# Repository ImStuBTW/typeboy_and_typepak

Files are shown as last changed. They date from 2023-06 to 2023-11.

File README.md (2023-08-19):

# The TypeBoy & TypePak

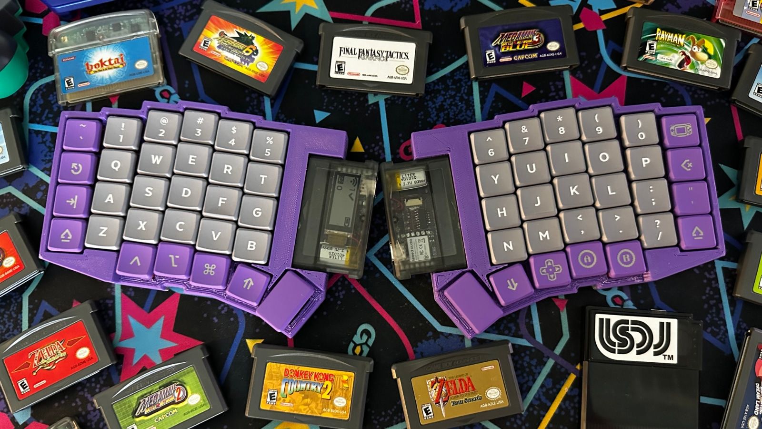
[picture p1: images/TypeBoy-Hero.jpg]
The TypeBoy & TypePak Laying Next To Several GBA Cartridges.


The TypeBoy is a fairly standard split ergonomic keyboard with a very non-standard microcontroller setup. Your eyes don't deceive you: This is a keyboard that needs a Game Boy Advance cartridge to function.

More specifically, it needs a TypePak! I've been spending a lot of time in the Ergogen keyboard layout generator lately, and I recently finished building a Sanni Open Source Cartridge Reader. These two worlds collided in my head and it dawned on me that a keyboard's microcontroller stack could probably fit in the shell of a Game Boy cartridge. A bit of tinkering in KiCAD later, and suddenly this monstrosity the TypePak was born.

## [The TypePak](typepak/README.md)

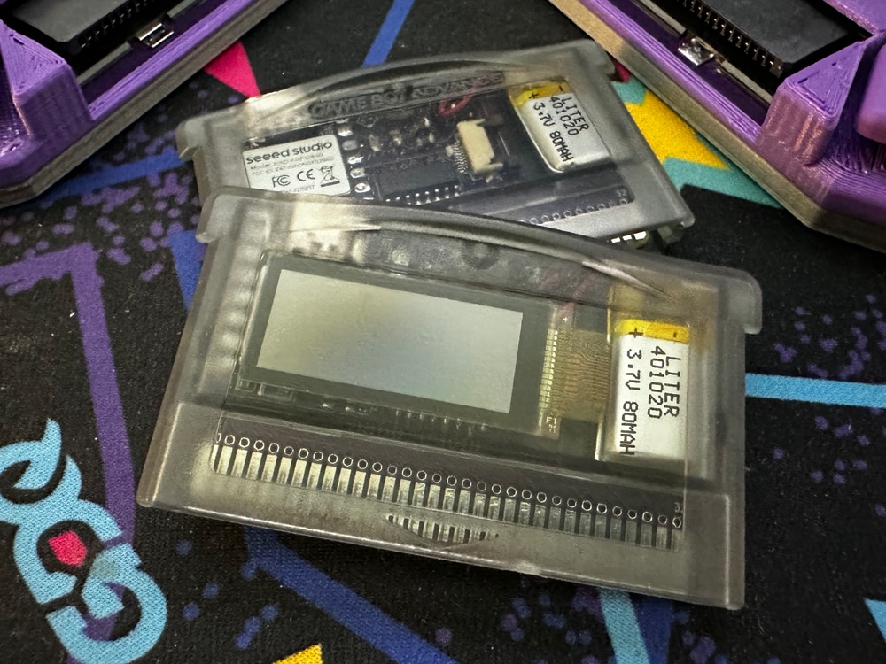
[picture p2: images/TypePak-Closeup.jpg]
The TypePak, a microcontroller and black and white display inside of a Game Boy Advance cartridge.


The TypePak is a keyboard daughterboard with a XIAO nRF52840 Bluetooth microcontroller, a SN74HC595DT shift register, a LS011B7DH03 Sharp Memory Display, and a 401020 lipo battery designed to be housed inside of a standard Game Boy Advance cartridge. Every pin is broken out in case you find some novel use for SPI, or chose not to use the screen. The battery trace and reset pins are also broken out so that you can put a power and reset switch on the main keyboard. You'll need to use a tool similar to a Dremel in order to cut a USB-C port in the side of the cartridge shell.

## [The TypeBoy](typeboy/README.md)

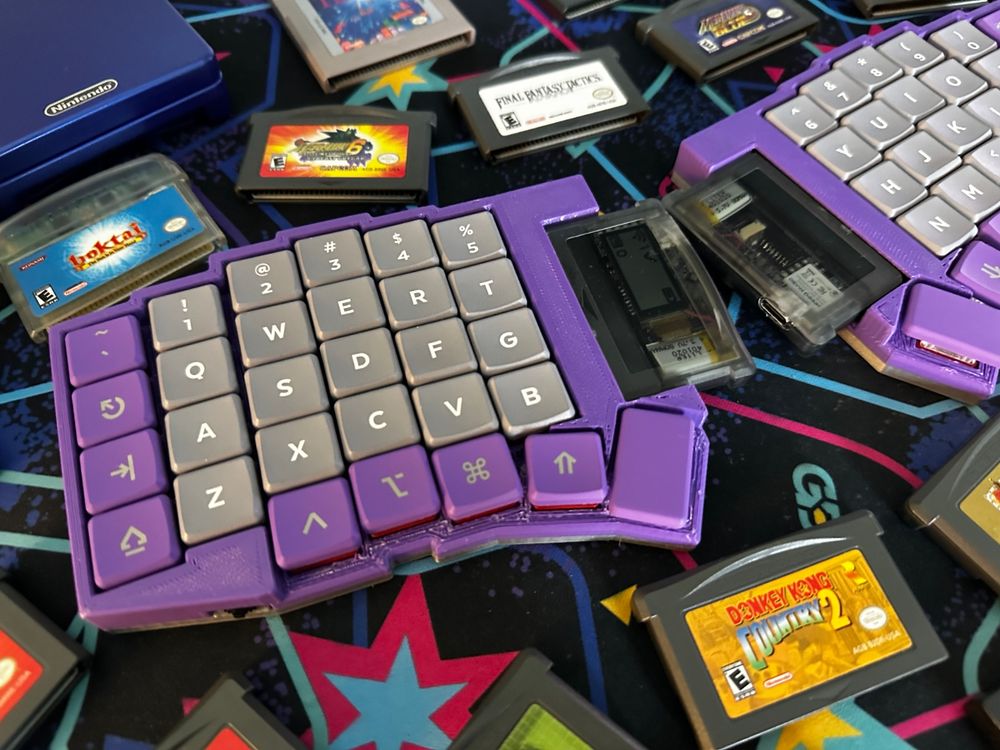
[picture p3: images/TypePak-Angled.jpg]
The TypeBoy, a keyboard with a cartridge slot.


The TypeBoy is a typical split keyboard with a 6x4+5 column staggered layout. The big difference being that it has a 32 pin slot for the Game Boy Advance cartridge. The connector appears on both sides of the board, with traces and vias making the connector pinout reversible. The other notable feature is a SLLB510100 thumb switch.

## [ZMK-Config](/zmk-config)

The ZMK wireless keyboard firmware configuration for this board is relatively standard. The software doesn't have any clue that it's being housed on an odd removable cartridge. Items to note are the LS011B7DH03 display using ZMK's built in Display support instead of the Nice!View wrapper one may be more familiar with, 74HC595 shift register support to add additional column output pins, and a [composite](https://zmk.dev/docs/config/kscan#composite-driver) key scan driver for using both a traditional keyboard matrix and direct pin reading for the thumb wheel.

## Acknowledgements

The TypeBoy isn't the first mechanical keyboard which takes microcontroller cartridges. [mujimanic](https://www.reddit.com/user/mujimanic/)'s [Giga40](https://www.reddit.com/r/MechanicalKeyboards/comments/kut2nk/now_youre_playing_with_power_giga40_power/) keyboard design and it's Famicom cartridges helped prove a low-profile Game Boy-centric version of this idea was worth pursuing.

The TypePak's display connector circuit is based off of [karnadii](https://github.com/karnadii)'s [Sharp Memory Display breakout board](https://github.com/karnadii/sharp_memory_display_breakout) design. The TypePak's PCB is based off of templates from [djedditt](https://github.com/djedditt/)'s [kicad-gamepaks](https://github.com/djedditt/kicad-gamepaks) library. The Game Boy cartridge slot KiCAD footprint was used from [Martin Refseth](https://github.com/HDR)'s [Game Boy KiCad Library](https://github.com/HDR/Game-Boy-KiCad-Library).

As usual, thanks to the [Absolem Club Discord](https://discord.gg/DbCfZfZ) and their #Ergogen channel for answering my endless onslaught of questions. Particularly special thanks to [Pete Johanson](https://github.com/petejohanson) for assisting with some ZMK troubleshooting when the low profile rotary encoders were giving me trouble. The ZMK firmware is heavily influenced by previous configs by [GEIST](https://github.com/GEIGEIGEIST/zmk-config-totem/tree/master/config), [Pete Johanson](https://github.com/petejohanson/zaphod-config/tree/main/boards/shields/zaphod_lite), and [JonMuller](https://github.com/JonMuller/gerbers/tree/main/corne-choc-xiao).

This keyboard is another derivative of [Josef Adamčík](https://josef-adamcik.cz/)'s original [Sofle Keyboard](https://josefadamcik.github.io/SofleKeyboard/) layout. I need to start experimenting with other layouts at this point, but it's hard to beat that thumb cluster.

Finally, another shout out to [GEIST](https://github.com/GEIGEIGEIST), [Freya](https://github.com/freya-irl), [Bubbleology](https://github.com/bubbleology) for their work on the [TOTEM](https://github.com/GEIGEIGEIST/TOTEM) keyboard's case. It was a big inspiration for this build, and they pulled the concept off way better than I did.

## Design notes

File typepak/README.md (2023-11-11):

# The TypePak

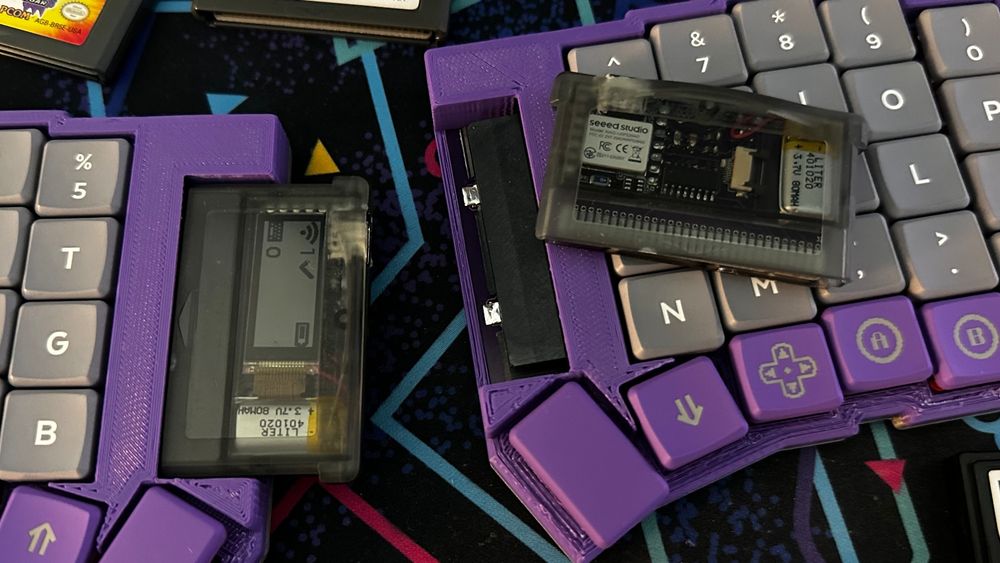
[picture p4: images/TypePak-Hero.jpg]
The TypePak microcontroller cartridge.


The TypePak is a custom keyboard controller PCB housed inside of an aftermarket Game Boy Advance cartridge shell. It features Bluetooth connectivity, ZMK support, a low-power monochrome display, a built in LiPo battery, 9 GPIO pins, and 8 dedicated output pins. Simply slot the TypePak into a keyboard with a compatible Game Boy cartridge slot, flip the power switch, and you've got yourself a working wireless keyboard. (After flashing the appropriate firmware and keymap, naturally.)

Unlike its companion TypeBoy, the TypePak was designed in KiCAD from scratch. Sadly there aren't any esoteric Game Boy cartridge generators just yet. This repository contains a standard KiCAD project. There's a schematic, a routed PCB, and a Gerber file.

## Layout & Pinout

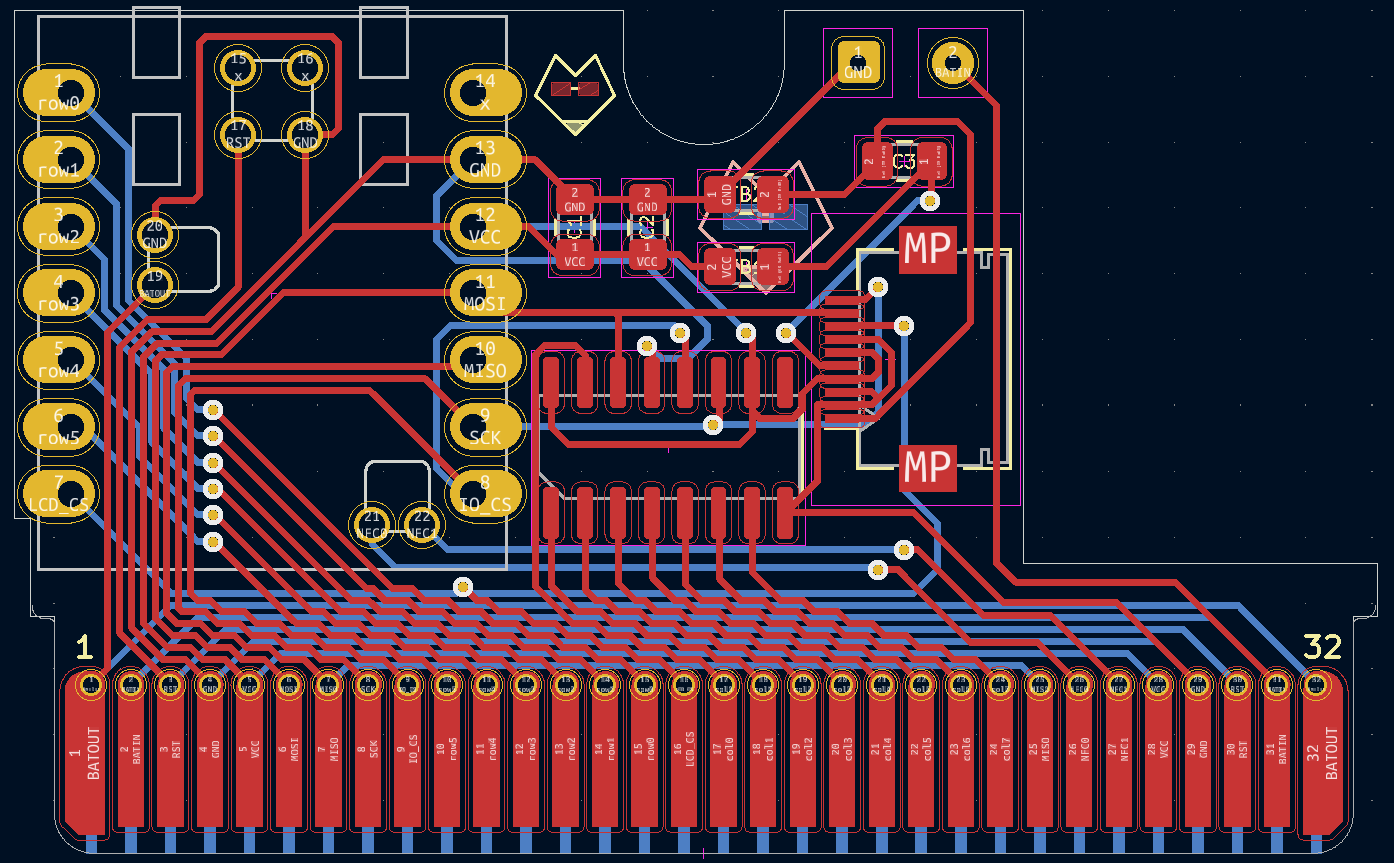
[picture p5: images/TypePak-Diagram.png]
The TypePak PCB layout.


The heart of the TypePak is a XIAO nRF52840 microcontroller. It handles all of the Bluetooth communication, the wireless battery charging, and USB connectivity. The XIAO "BLE" famously has several pins mounted in the middle of the board on its underside, so the TypePak has several small holes in the PCB to reach the reset, power, and NFC pins.

There's a few additional pieces of hardware mounted onto the board. The TypePak features a LS011B7DH03 Sharp Memory Display. This is the same module found on the Nice!View keyboard display, but instead leverages karnadii's excellent [sharp_memory_display_breakout](https://github.com/karnadii/sharp_memory_display_breakout) circuit design. The microcontroller also takes advantage of a 74HC595 shift register to provide several more output pins. All of this is powered by a 401020 LiPo battery.

A Game Boy cartridge has 32 pins on its edge connector. The XIAO nRF52840 and the shift register have a total of 26 pins. Rather than leave twenty precent of the TypePak's cartridge pins unused, several of the important pins are exposed on both ends of the cartridge's edge connector. The battery output, power pins, reset pins, and a few others are duplicated so that you can more easily route some of the support hardware on your keyboard PCB.

Speaking of which, the TypePak does not have a built in power switch or reset button of its own. (Technically the XIAO does have a reset button, but it's underneath the cartridge's plastic casing.) You'll need to create out these components on the keyboard itself. The whole idea of this setup is to evoke the stylings of a classic Game Boy, so a large chunky power switch is honestly a welcome addition. Just remember, the battery is physically disconnected unless the keyboard's power switch is turned on, so the TypePak can't charge when disconnected from a board.

## Building a TypePak

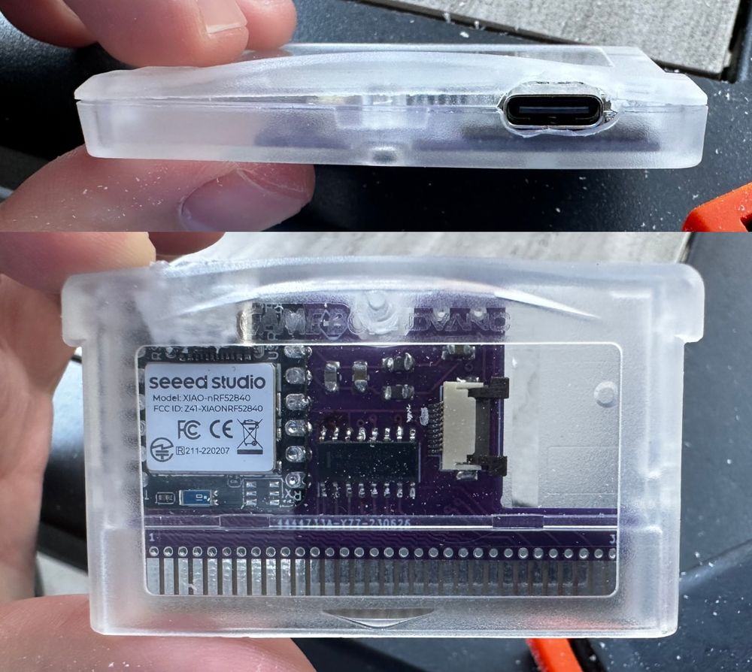
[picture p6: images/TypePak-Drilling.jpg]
The TypePak inside of a plastic cartridge case.


The TypePak is enclosed inside of an aftermarket Game Boy Advance cartridge. Believe it or not, these cartridges typically did not feature cutouts for USB-C ports. You'll need to drill one into the side of your cartridge so that the TypePak can charge and be flashed with new firmware.

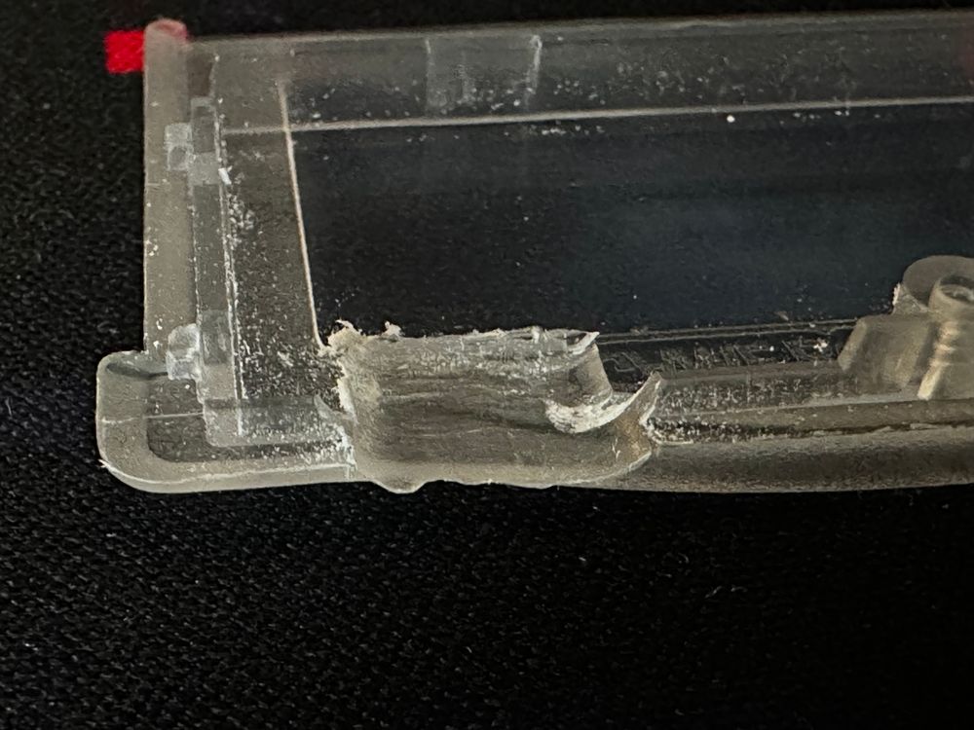
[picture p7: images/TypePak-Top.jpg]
The top half of the TypePak's case with several millimeters of plastic shaved away.


Cutting a hole in the side of the cartridge won't be enough. You'll also need to shave away some of the inside of the top of the case. You should be able to leave most of the exterior of the top untouched. There's *just* enough material on the inside of the case to make everything fit. The cartridge may bow slightly, but you should be able to get all the tabs locked securely into place and the fastener screw fully secured into place. Aftermarket cartridges are fairly cheap, so you may want to buy an extra to practice on.

## Build of Materials

| Part | Amount | Price | Link |
| --- | --- | --- | ---- |
| TypePak PCB Via JLCPCB | 1 (5 PCB Pack) | $2-4.00 USD | https://jlcpcb.com |
| XIAO nRF52840 Microcontroller | 1 | $10.00 USD  | https://www.digikey.com/en/products/detail/seeed-technology-co-ltd/102010448/16652893 |
| HFK110CT-ND Display Connector | 1 | $1.35 USD | https://www.digikey.com/en/products/detail/hirose-electric-co-ltd/FH12A-10S-0-5SH-55/1110331 |
| 560PF Capacitor | 2 | $0.15 USD | https://www.digikey.com/en/products/detail/samsung-electro-mechanics/CL21C561JBANNNC/3887492 |
| 1UF Capacitor | 2 | $0.10 USD | https://www.digikey.com/en/products/detail/samsung-electro-mechanics/CL21B105KBFNNNG/3894467 |
| 300 OHM Ferrite Beads | 2 | $0.20 USD | https://www.digikey.com/en/products/detail/vishay-dale/ILBB0805ER301V/2574914 |
| SN74HC595 Shift Register | 1 | $1.00 USD | https://www.digikey.com/en/products/detail/texas-instruments/SN74HC595DT/1571266 |
| LS011B7DH03 Sharp Memory Display | 1 | $15.00 USD  | https://www.aliexpress.us/item/3256801622787441.html |
| 401020 LiPo Battery (80 mAh) | 1 | $7.00 USD | https://www.amazon.com/gp/product/B09FLX9VZD/ |
| Game Boy Advance Cartridge Shell | 1 | $3.50 USD | https://www.aliexpress.us/item/3256803793023444.html |

The above table represents the parts needed to construct a single TypePak. You'll need to double everything except for the PCB order if you plan on making two. (JLCPCB fabricates PCBs in groups of 5 as a minimum.) If you're building two TypePaks, it's probably worth bumping the capacitor and ferrite bead orders up to 10. You don't want to have your entire project get stalled if you misplace one of the small components, and the bulk ordering pricing makes buying 4-6 units approximately the same cost as 10.

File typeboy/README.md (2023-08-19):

# The TypeBoy

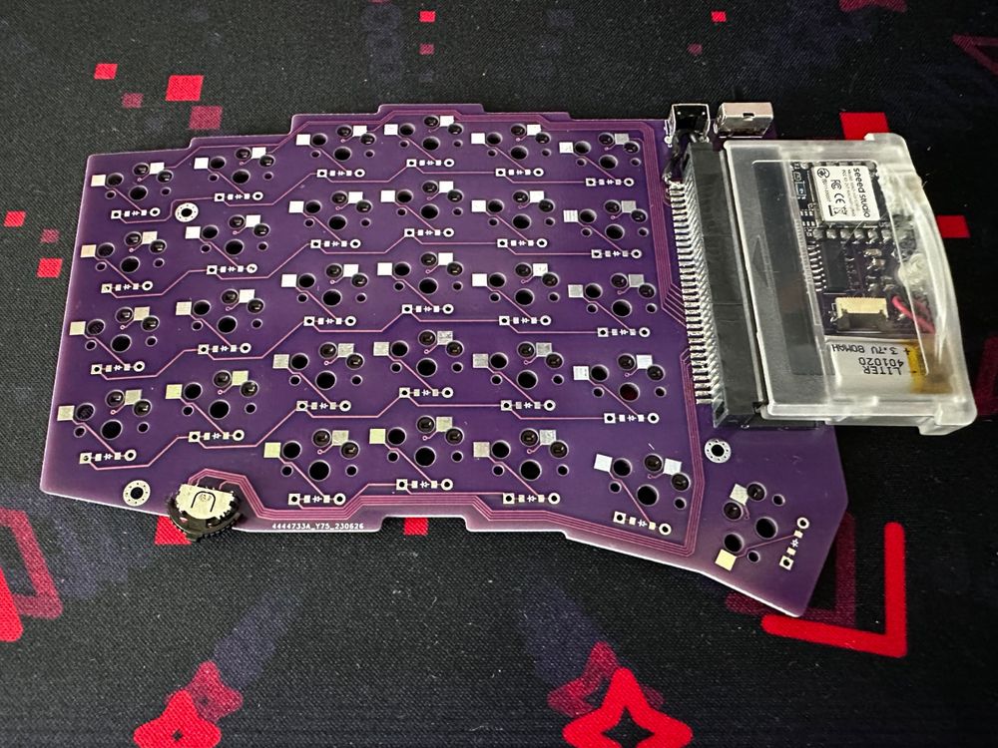
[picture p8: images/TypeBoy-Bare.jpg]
The TypeBoy outside of its case.


The TypeBoy is a four row, six column, five modifier column staggered split ergonomic keyboard. A 6x4+5 layout as the cool kids would say. Stop me if you've heard this one before, but it was inspired by [Josef Adamčík](https://josef-adamcik.cz/)'s [Sofle keyboard](https://josefadamcik.github.io/SofleKeyboard/).

This keyboard was designed mostly as a testbed for the TypePak microcontroller cartridge. It doesn't have too much going on outside of the Game Boy slot on the side. The only other peculiar hardware feature is the SLLB510100 thumb switch. It's a low profile slide switch that you can rotate to the left or right as well as pushing straight in. It's similar in purpose to a rotary encoder, but it just rocks back and forth instead of spinning. If you used a CD player around the turn of the century you probably know what to expect.

## Ergogen Outputs

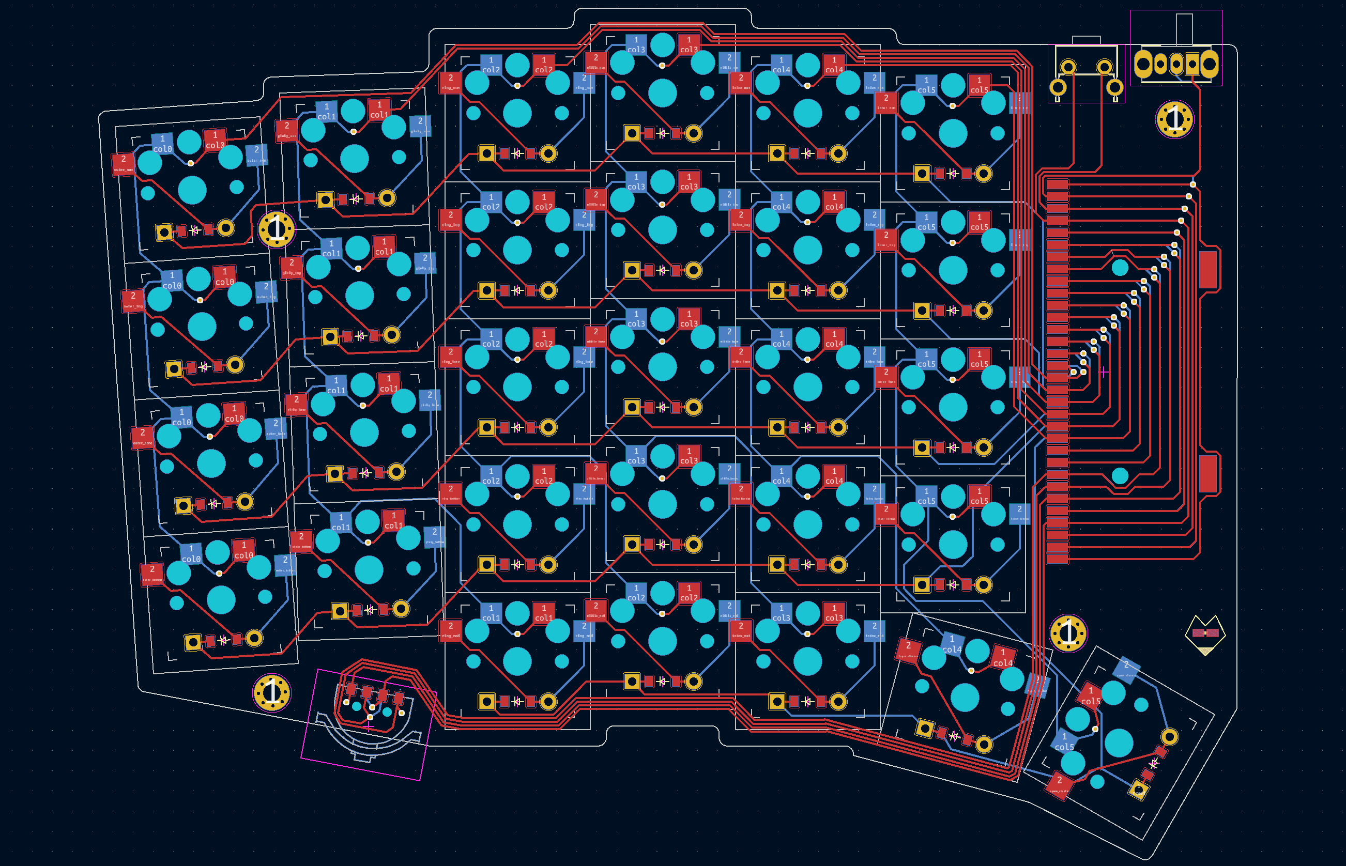
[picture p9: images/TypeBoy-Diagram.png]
The TypeBoy PCB Diagram.


It should come as no surprise that I leveraged [Ergogen](https://github.com/ergogen/ergogen) to design the TypeBoy. The ergonomic keyboard generator makes it easy to turn keyboard concepts into full fledged designs. I wrote a whole blog post about it if you’re interested.

The TypeBoy uses several custom footprints. Most notably, the large Game Boy cartridge slot. To use these config files, clone this repository and install Ergogen onto your local system. Browse to this TypeBoy folder and run `ergogen .`to process `config.yaml`.

The primary output is the TypeBoy PCB. Ergogen will create an unrouted KiCAD file, but I’ve gone ahead and included the fully routed board in the repository. The resulting Gerber files are also included if you want to run the board off without any modifications.

Ergogen also has the ability to output vector outline files or 3D case files. The TypeBoy’s config outputs several outlines, but the case design I had in mind for this board were a little too complicated tor Ergogen itself. I ended up building the TypeBoy’s case in AutoDesk Fusion 360.

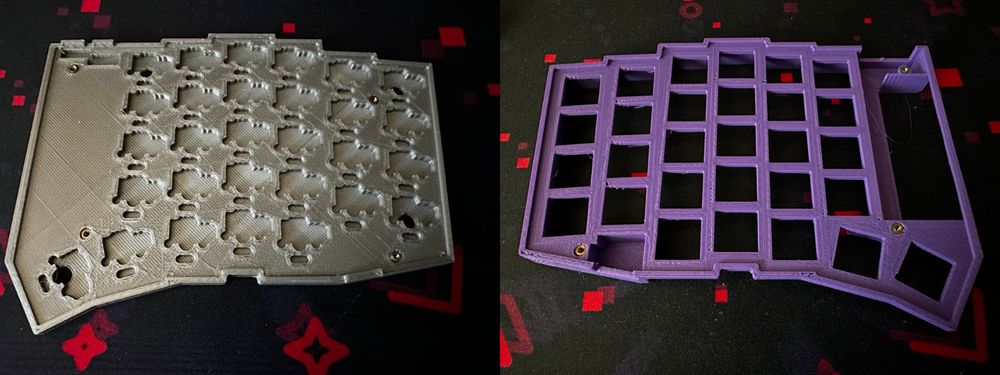
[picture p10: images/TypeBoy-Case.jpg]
The TypeBoy's Case


There’s one unusual output Ergogen produces in this design. It makes a “backplate” PCB. This is a bit of an unusual concept I’ve experimented with for my last few builds. It’s loosely based off the [Horizon](https://github.com/skarrmann/horizon) keyboard, with the intention of providing cutouts for diodes and footprint switches when building a case.

Unlike the Horizon, I just export the PCB design as a `.step` file and then use an online tool to convert the file into a `.stl` file I can e corporate into a 3D printed case design. The end result is a bottom piece that perfectly fits the components without providing a lot of echo-y blank space.

The case output folder has three files. The bottom pieces aren’t symmetrical. (The hotswap sockets aren’t flipped.) The top piece is symmetrical, so you can just flip it in your 3D printing software of choice before sending it though. The top and bottom pieces use seven M2 heat set screw inserts.

## Additional Footprints

Ergogen v4 supports custom footprints! The TypeBoy colors outsides the lines and includes a few not included in the standard repo:

* buttonrightangle.js - A right angle pushbutton.
* gbareversible.js - A reversible game boy cartridge slot footprint based off of [Martin Refseth's KiCAD footprint](https://github.com/HDR/Game-Boy-KiCad-Library/blob/master/Footprints/DSL_Cartridge_Reader.kicad_mod).
* lowproro.js - A footprint for the SIQ-02FVS3 low profile rotary encoder. Used in an earlier TypeBoy design.
* lowprothumb.js - A footprint for the SLLB510100 thumb switch used on later TypeBoy builds.
* mountinghole.js - An M2 mounting hole footprint.

There's also several "backplate" footprints. These are footprints which just have an edge cut drawn around the space where the standard component goes. `diode.js` handles the diodes, `diodebackplate.js` handles the cutout. Etc. Creating these as footprints rather than Ergogen outlines makes it a bit easier to place each backplate cutout exactly where the corresponding component goes.

## Build of Materials

| Part | Amount | Price | Link |
| --- | --- | --- | ---- |
| TypeBoy PCB Via JLCPCB | 1 (5 PCB Pack) | $20.00 USD (Incl. Slow Shipping) | https://jlcpcb.com |
| Game Boy Cartridge Slot | 2 | $5.00 USD  | https://www.aliexpress.us/item/2255800103876564.html |
| SLLB510100 Thumb Switch | 2 | $8.00 USD | https://www.mouser.com/ProductDetail/Hirose-Connector/FH12A-10S-0.5SH55 |
| Right Angle Pushbutton | 2 | $1.00 USD | https://www.mouser.com/ProductDetail/642-MJTP1117 |
| Right Angle Switch | 2 | $1.50 USD | https://www.mouser.com/ProductDetail/612-EG1213 |
| Choc Hotswap Sockets | 58 | $12.00 USD  | https://www.aliexpress.us/item/3256803687338432.html |
| 1N4148 T4 Diodes | 58 | $3.00 USD | https://www.aliexpress.us/item/2255800498728983.html |
| Choc Switches | 58 | $28.00 USD  | https://www.aliexpress.us/item/3256805260407528.html |
| Choc Keycaps | Alphas + Mods  | $~60.00 USD | https://mkultra.click/mbk-legend-keycaps/ |
| 3D Printed Case | Buy Your Buddy Some Filament | $~20.00 USD | https://github.com/ImStuBTW/typeboy_and_typepak/tree/main/typeboy/output/case |
| Bumpons | 1 Pack  | $10.00 USD | https://www.amazon.com/Adhesive-Bumper-106-PC-Spherical-Square/dp/B06XPCLN23/ |

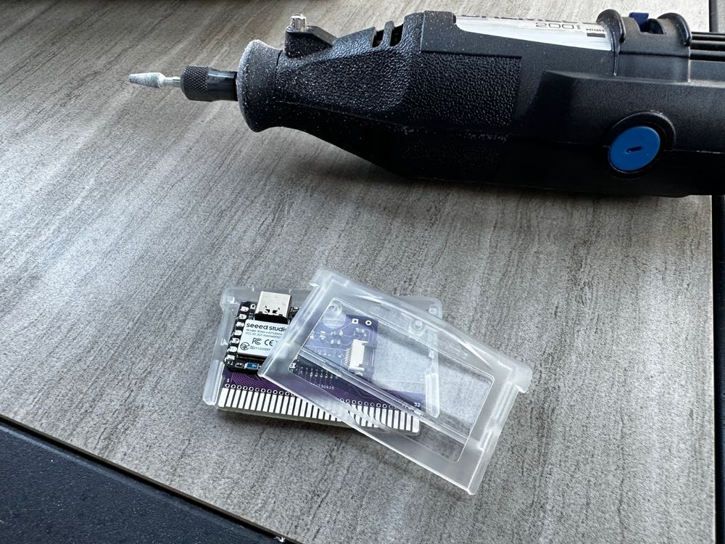
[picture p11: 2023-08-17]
images/TypePak-Dremel.jpg

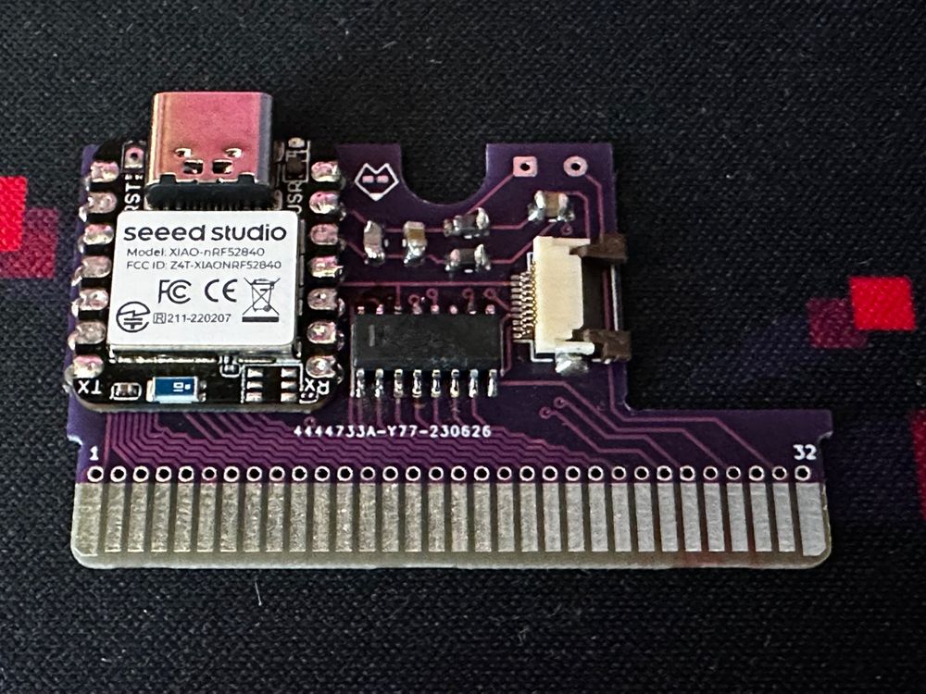
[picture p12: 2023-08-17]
images/TypePak-PCB.jpg

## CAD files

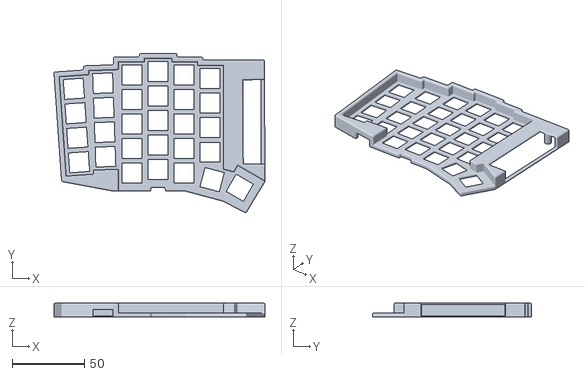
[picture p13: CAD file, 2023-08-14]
typeboy/output/case/TypeBoy-Top.stl
146.2 x 110.4 x 9.60

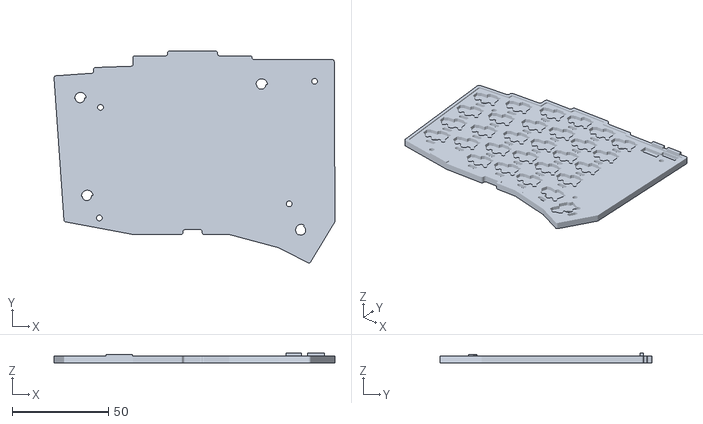
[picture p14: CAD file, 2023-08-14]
typeboy/output/case/TypeBoy-Bottom-Right.stl
146.2 x 110.4 x 5.40

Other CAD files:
typeboy/output/case/TypeBoy-Bottom-Left.stl

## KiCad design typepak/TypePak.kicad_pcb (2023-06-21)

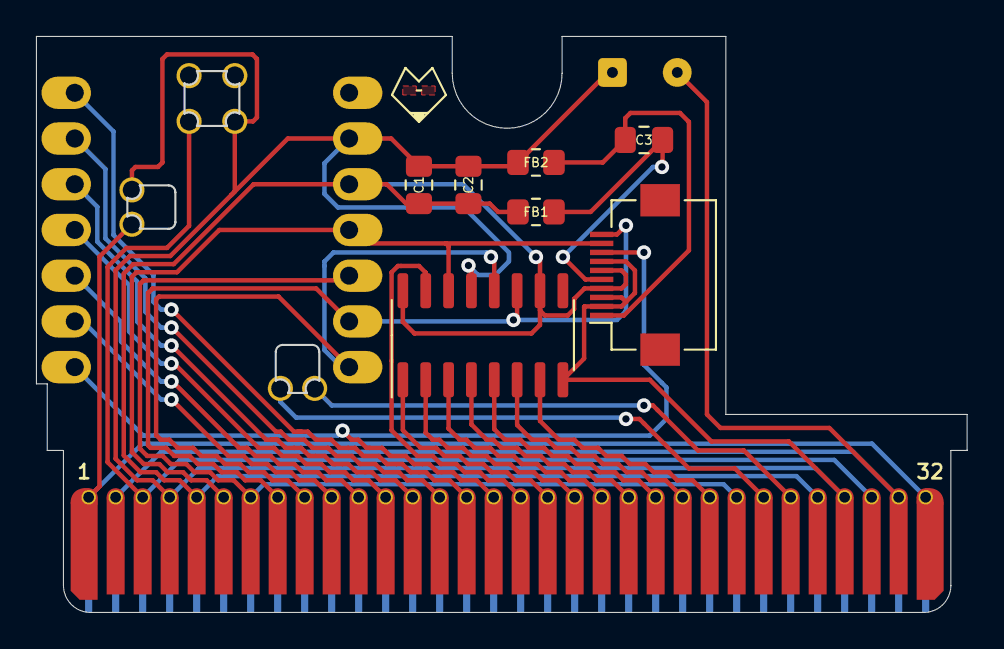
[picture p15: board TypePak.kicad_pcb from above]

Board: 2 copper layers, 51.7 x 32.0 mm, 10 parts (0 on the bottom side), 28 nets.

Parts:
C1: 560pF/680pF; C_0805_2012Metric_Pad1.18x1.45mm_HandSolder
C2, C3: 1uF; C_0805_2012Metric_Pad1.18x1.45mm_HandSolder
FB1, FB2: FerriteBead_Small; R_0805_2012Metric_Pad1.20x1.40mm_HandSolder
J1: Conn_01x32_Male; GameBoy_GamePak_AGB-002_P1.50mm_Edge
J2: Conn_01x02_Female; SolderWire-0.1sqmm_1x02_P3.6mm_D0.4mm_OD1mm
J3: Conn_01x10; Hirose_FH12-10S-0.5SH_1x10-1MP_P0.50mm_Horizontal
U1: xiao-ble; xiao-ble-smd-cutout-nfc
U2: 74HC595; SOIC-16_3.9x9.9mm_P1.27mm

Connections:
BATIN: J1.2, J1.31, J2.2
BATOUT: J1.1, J1.32, U1.19 (BAT)
GND: C1.2, C2.2, FB2.1, J1.4, J1.29, J2.1, J3.4, J3.8, J3.9, U1.13 (GND), U1.18 (GND), U1.20 (GND), U2.8 (GND), U2.13 (~OE)
IO_CS: J1.9, U1.8 (B9_RX/1.12), U2.12 (RCLK)
LCD_CS: J1.16, J3.3, U1.7 (B8_TX/1.11)
MISO: J1.7, J1.25, U1.10 (A5_MISO/1.14)
MOSI: J1.6, J3.2, U1.11 (A6_MOSI/1.15), U2.14 (SER)
NFC0: J1.26, U1.21 (NFC1/0.09_H)
NFC1: J1.27, U1.22 (NFC2/0.10_H)
unnamed: C3.1, FB1.1, J3.6
unnamed: C3.2, FB2.2, J3.10
RST: J1.3, J1.30, U1.17 (RESET)
SCK: J1.8, J3.1, U1.9 (A7_SCK/1.13), U2.11 (SRCLK)
VCC: C1.1, C2.1, FB1.2, J1.5, J1.28, J3.5, J3.7, U1.12 (3V3), U2.10 (~SRCLR), U2.16 (VCC)
col0: J1.17, U2.15 (QA)
col1: J1.18, U2.1 (QB)
col2: J1.19, U2.2 (QC)
col3: J1.20, U2.3 (QD)
col4: J1.21, U2.4 (QE)
col5: J1.22, U2.5 (QF)
col6: J1.23, U2.6 (QG)
col7: J1.24, U2.7 (QH)
row0: J1.15, U1.1 (A2/0.02_H)
row1: J1.14, U1.2 (A4/0.03_H)
row2: J1.13, U1.3 (A10/0.28)
row3: J1.12, U1.4 (A11/0.29)
row4: J1.11, U1.5 (A8_SDA/0.04_H)
row5: J1.10, U1.6 (A9_SCL/0.05_H)

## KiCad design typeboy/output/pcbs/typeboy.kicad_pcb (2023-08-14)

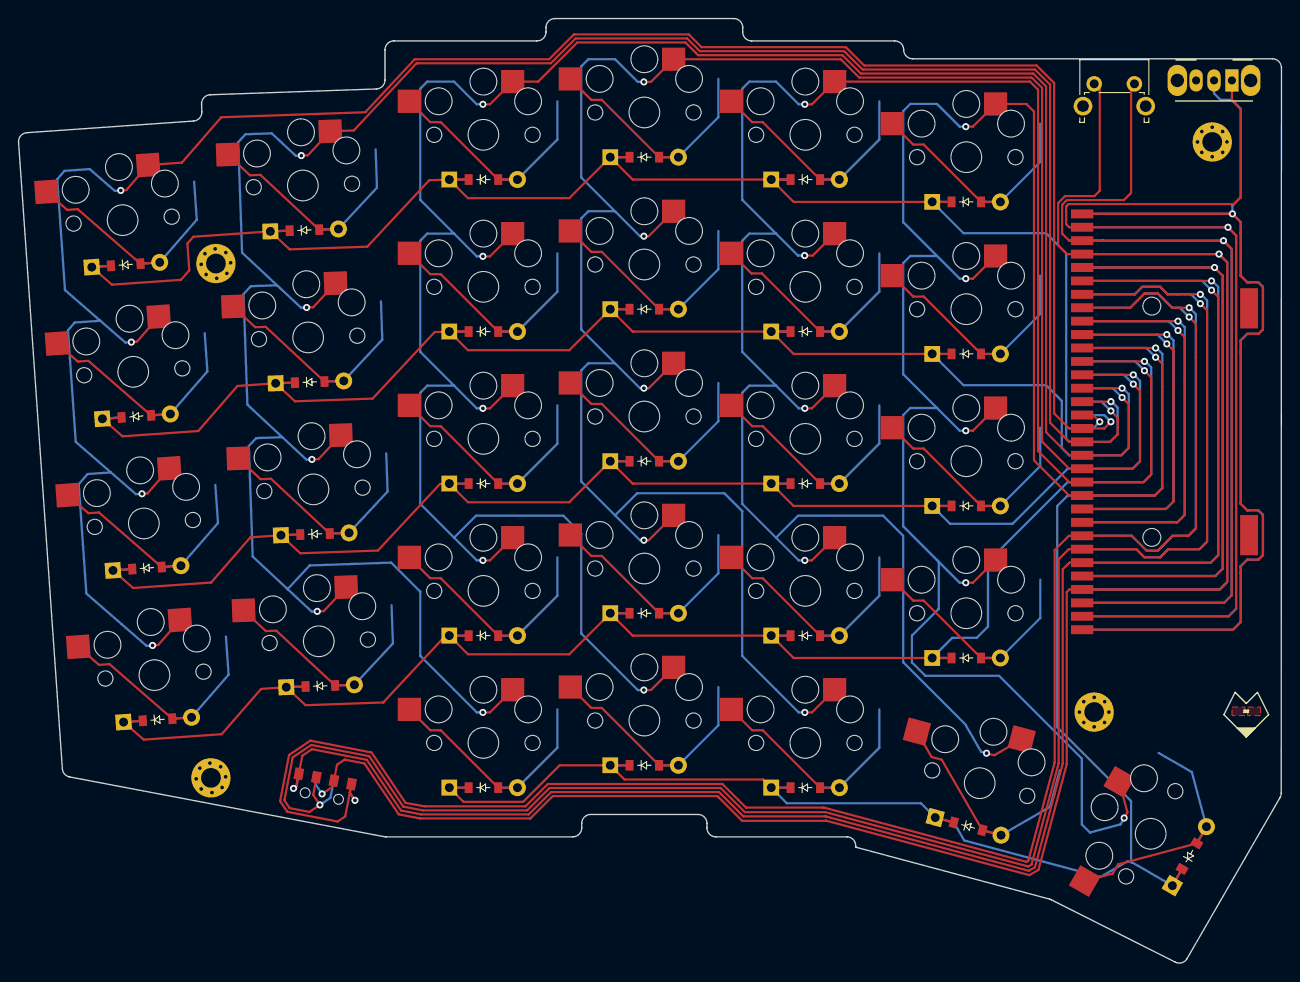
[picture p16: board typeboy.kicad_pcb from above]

Board: 2 copper layers, 141.2 x 105.6 mm, 64 parts (0 on the bottom side), 55 nets.

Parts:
D1, D2, D3, D4, D5, D6, D7, D8, D9, D10, D11, D12, D13, D14, D15, D16, D17, D18, D19, D20, D21, D22, D23, D24, D25, D26, D27, D28, D29: ComboDiode
J2: CartBus; GBA_Reversible_Cart_Reader
S1, S2, S3, S4, S5, S6, S7, S8, S9, S10, S11, S12, S13, S14, S15, S16, S17, S18, S19, S20, S21, S22, S23, S24, S25, S26, S27, S28, S29: PG1350
S**: SLLB510100
_1, _2, _3, _4: MountingHole_2.2mm_M2_Pad_Via

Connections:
BATIN: J2.2, J2.31, J2.34, J2.63
BATOUT: J2.1, J2.32, J2.33, J2.64
GND: J2.4, J2.29, J2.36, J2.61, S**.C1, S**.T1
IO_CS: J2.9, J2.56
LCD_CS: J2.16, J2.49
MISO: J2.7, J2.25, J2.40, J2.58, S**.1
MOSI: J2.6, J2.59
NFC0: J2.26, J2.39, S**.C1, S**.T1
NFC1: J2.27, J2.38, S**.2
RST: J2.3, J2.30, J2.35, J2.62
SCK: J2.8, J2.57
VCC: J2.5, J2.28, J2.37, J2.60
col0: J2.17, J2.48, S1.1, S2.1, S3.1, S4.1
col1: J2.18, J2.47, S5.1, S6.1, S7.1, S8.1, S9.1
col2: J2.19, J2.46, S10.1, S11.1, S12.1, S13.1, S14.1
col3: J2.20, J2.45, S15.1, S16.1, S17.1, S18.1, S19.1
col4: J2.21, J2.44, S20.1, S21.1, S22.1, S23.1, S28.1
col5: J2.22, J2.43, S24.1, S25.1, S26.1, S27.1, S29.1
col6: J2.23, J2.42
col7: J2.24, J2.41
index_bottom: D20.2, S20.2
index_home: D21.2, S21.2
index_mod: D19.2, S19.2
index_num: D23.2, S23.2
index_top: D22.2, S22.2
inner_bottom: D24.2, S24.2
inner_home: D25.2, S25.2
inner_num: D27.2, S27.2
inner_top: D26.2, S26.2
layer_cluster: D28.2, S28.2
middle_bottom: D15.2, S15.2
middle_home: D16.2, S16.2
middle_mod: D14.2, S14.2
middle_num: D18.2, S18.2
middle_top: D17.2, S17.2
outer_bottom: D1.2, S1.2
outer_home: D2.2, S2.2
outer_num: D4.2, S4.2
outer_top: D3.2, S3.2
pinky_bottom: D5.2, S5.2
pinky_home: D6.2, S6.2
pinky_num: D8.2, S8.2
pinky_top: D7.2, S7.2
ring_bottom: D10.2, S10.2
ring_home: D11.2, S11.2
ring_mod: D9.2, S9.2
ring_num: D13.2, S13.2
ring_top: D12.2, S12.2
row0: D4.1, D8.1, D13.1, D18.1, D23.1, D27.1, J2.15, J2.50
row1: D3.1, D7.1, D12.1, D17.1, D22.1, D26.1, J2.14, J2.51
row2: D2.1, D6.1, D11.1, D16.1, D21.1, D25.1, J2.13, J2.52
row3: D1.1, D5.1, D10.1, D15.1, D20.1, D24.1, J2.12, J2.53
row4: D9.1, D14.1, D19.1, D28.1, D29.1, J2.11, J2.54
row5: J2.10, J2.55
space_cluster: D29.2, S29.2

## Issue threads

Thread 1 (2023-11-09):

Wrong link in typepak readme

ZoeArch, 2023-11-09:
in `typepak/README.md` the line 41 the link to the shift register is instead a duplicate of line 40's link to the 300 OHM Ferrite Beads

ZoeArch, 2023-11-09:
the correct link should be https://www.digikey.com/en/products/detail/texas-instruments/SN74HC595DT/1571266, as this is the link provided in the blog post

ImStuBTW, 2023-11-11:
Thanks, the link's been updated!

Closed 2023-11-11.

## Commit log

2023-06-17 Switched to `col2row`.
2023-06-21 Encoder Testing.
    [TypePak-B_Cu.gbr, TypePak-B_Mask.gbr, TypePak-B_Paste.gbr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]
2023-08-14 Updated Documentation.
    [TypeBoy-Bottom-Left.stl, TypeBoy-Bottom-Right.stl, TypeBoy-Top.stl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]
2023-08-18 Build of Materials
